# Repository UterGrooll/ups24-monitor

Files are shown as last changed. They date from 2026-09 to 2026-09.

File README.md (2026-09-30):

# UPS 24V Monitor

Контроллер мониторинга ИБП **Штиль PS2420G** на Arduino Nano: измерение напряжения шины 24 В, температуры АКБ и состояния двух сухих контактов. Данные передаются по UART на внешний контроллер для дальнейшего опроса из SCADA.

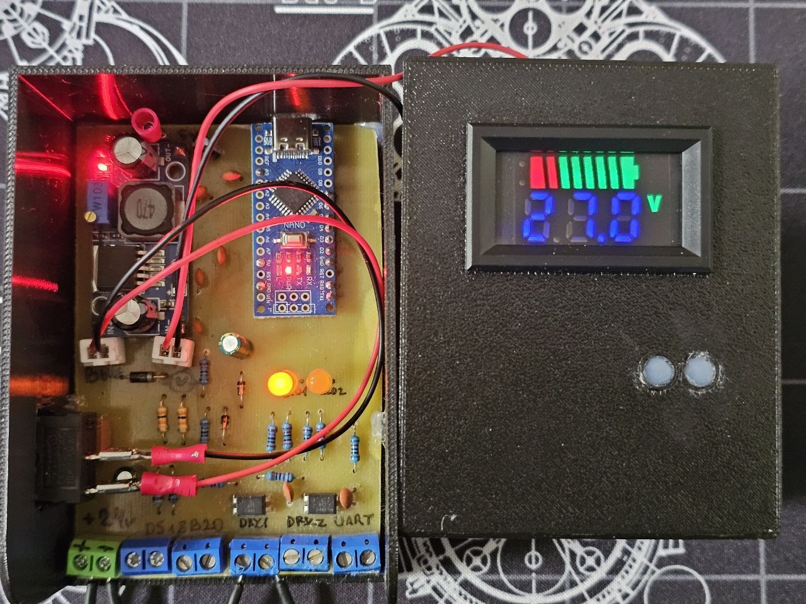
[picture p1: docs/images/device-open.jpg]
Контроллер в корпусе


## Возможности

- Один канал измерения напряжения **0…30 В**.
- Внешний датчик температуры **DS18B20**.
- Два входа сухих контактов через **PC817** с LED-индикацией.
- Выход **UART 9600 бод**, значения в целочисленном формате.
- Питание через понижающий модуль **LM2596S**, выход 5 В.
- Корпусной индикатор напряжения и съёмный выключатель.
- Плата KiCad для одностороннего травления; корпус FreeCAD и файлы 3D-печати.

> Эта плата сама не реализует Modbus TCP и не подключается к Ethernet.
> UART принимает отдельный контроллер-шлюз. Два контакта ИБП не означают два независимых канала измерения напряжения — АЦП-канал здесь один.

## Аппаратная часть

| Узел | Исполнение |
| --- | --- |
| Контроллер | Arduino Nano, ATmega328P, логика 5 В |
| Питание | Шина ИБП около 27 В → LM2596S → 5 В |
| Делитель | 30 кОм + 30 кОм / 10 кОм, номинальный коэффициент 7 |
| Температура | DS18B20, трёхпроводное подключение |
| Дискретные входы | 2 × PC817 |
| Интерфейс | Однонаправленный TTL UART |
| Проект платы | KiCad 10 |
| Корпус | FreeCAD, 3MF |

### Выводы Nano

| Сигнал | Пин |
| --- | --- |
| Напряжение через делитель | A0 |
| DS18B20 DATA | D7 |
| Контакт ИБП 1 | D6 |
| Контакт ИБП 2 | D5 |
| UART TX | D1/TX |
| Общий провод | GND |

D0/RX для текущей прошивки не используется. Пины относятся к **измерительной Nano**, не к внешнему ПАК.

## Фотографии

| Плата | Проверка UART |
| --- | --- |
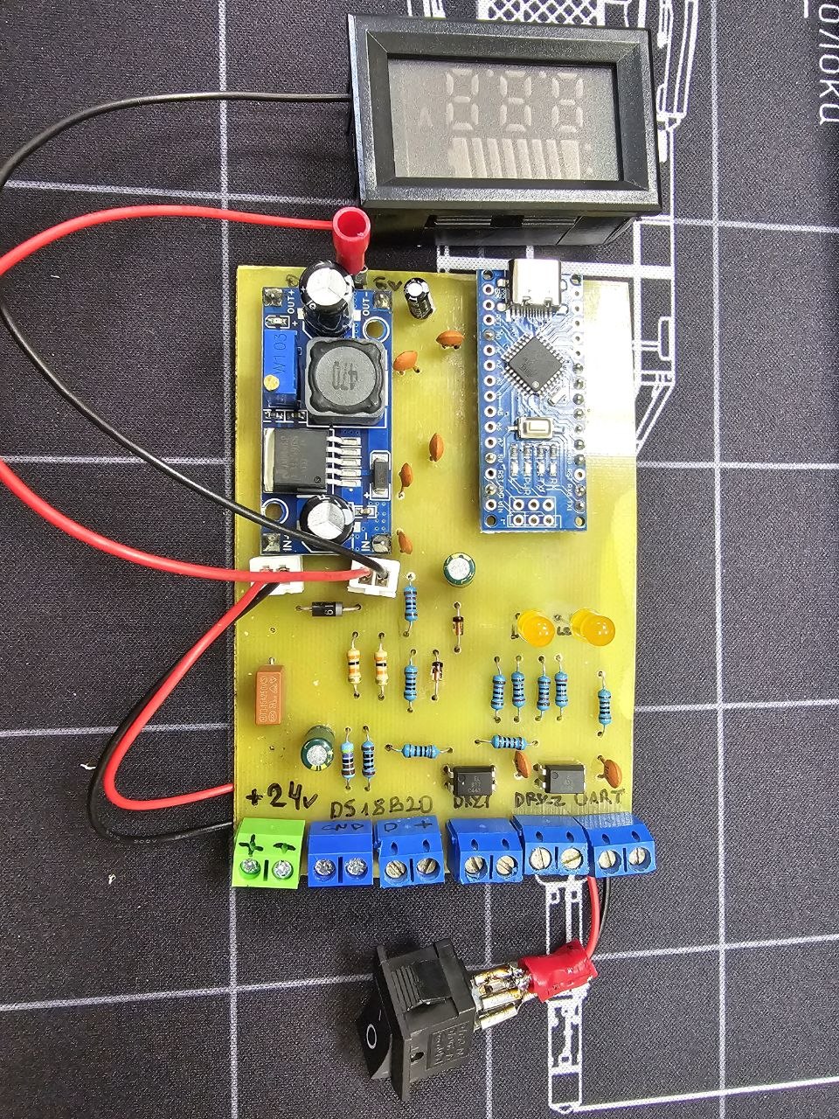
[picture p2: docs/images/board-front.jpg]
Плата
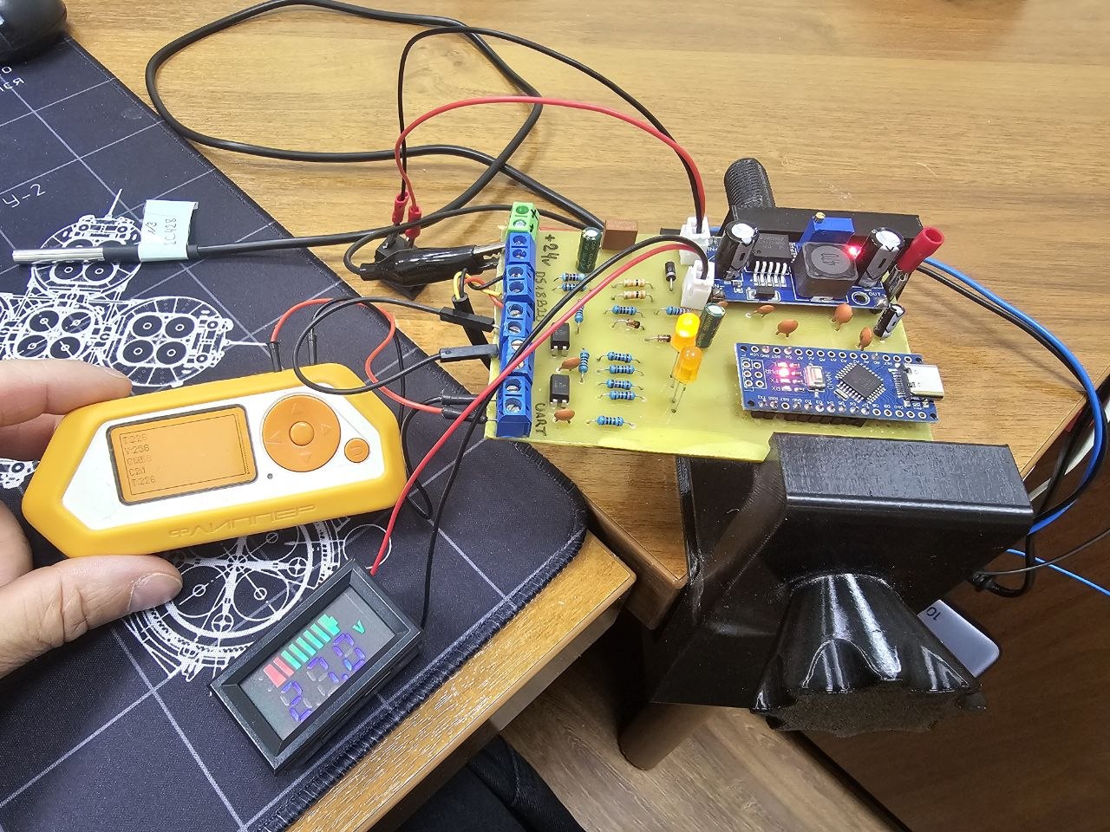
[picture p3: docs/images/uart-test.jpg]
Стендовая проверка
|  |  |

| Разводка | Корпус |
| --- | --- |
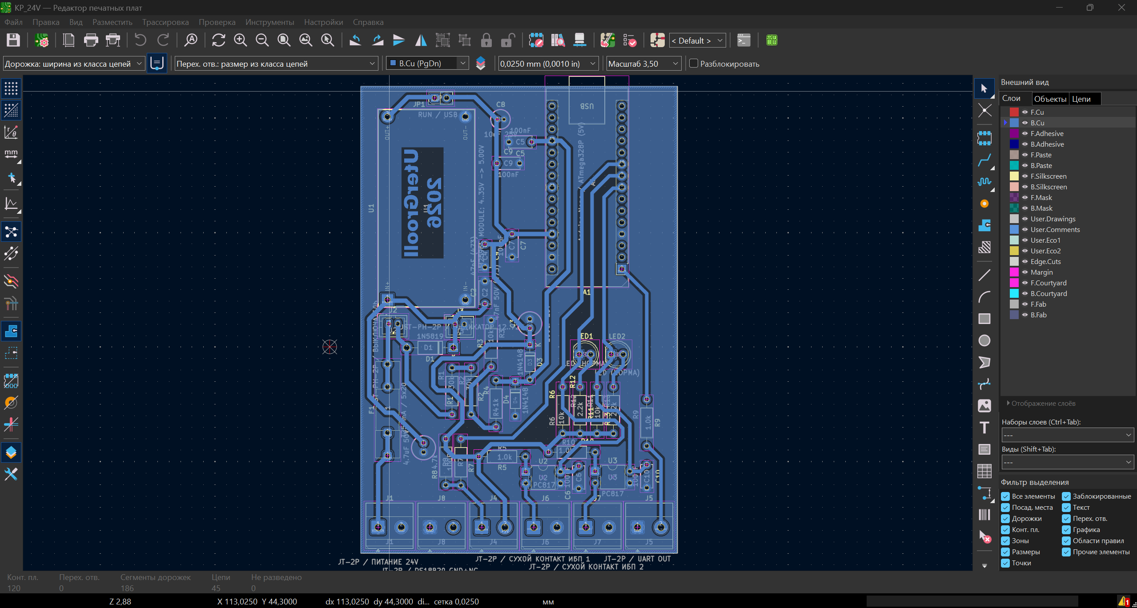
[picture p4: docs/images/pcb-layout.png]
Разводка платы
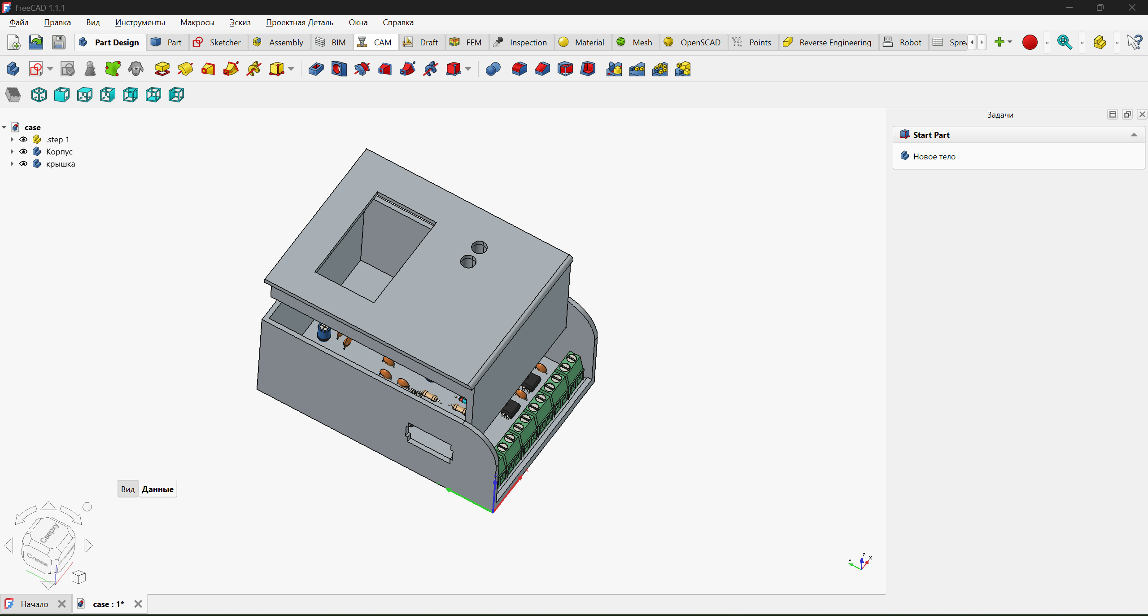
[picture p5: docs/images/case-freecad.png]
Корпус FreeCAD
|  |  |

[Все фотографии и изображения](docs/images/) взяты из материалов сборки. Фото и скриншоты могут отражать промежуточные этапы; перед изготовлением сверяйте их с исходниками KiCad.

## Прошивка

Скетч: [firmware/KP_24V/KP_24V.ino](firmware/KP_24V/KP_24V.ino).

1. Открыть скетч в Arduino IDE.
2. Установить библиотеку **GyverDS18**.
3. Выбрать Arduino Nano и загрузчик, соответствующий установленной плате.
4. Проверить безопасное питание при USB-подключении, затем загрузить скетч.
5. Открыть монитор порта на **9600 бод**.

Библиотеки Ethernet и ModbusTCP_RU на этой Nano не требуются. Логика существующего скетча при подготовке репозитория не изменялась.

### Калибровка напряжения

В скетче сохранена двухточечная калибровка конкретного макета:

| Входное напряжение | Значение АЦП |
| --- | ---: |
| 5,0 В | 144 |
| 30,0 В | 880 |

Константы `VOLTAGE_CAL_LOW_DV = 50` и `VOLTAGE_CAL_HIGH_DV = 300` заданы в десятых долях вольта. Для другой платы и источника 5 В нужно повторить измерения и изменить калибровку. Шаг вывода 0,1 В не означает гарантированную точность 0,1 В.

## UART и SCADA

Пример потока:

```text
V:270
T:234
C1:0
C2:1
```

Это 27,0 В, 23,4 °C, нормальное состояние ИБП 1 и авария/размыкание контакта ИБП 2.

Полный формат, подключение и различия карт регистров внешних приёмников описаны в [docs/uart.md](docs/uart.md).

Для стендового Modbus TCP-приёмника используется отдельный проект [SCADA Modbus TCP Relay Timer](https://github.com/UterGrooll/scada-modbus-tcp-relay-timer) на базе [ModbusTCP_RU](https://github.com/UterGrooll/ModbusTCP_RU). Исходники этого приёмника не включены в данный репозиторий.

## Схема, плата и корпус

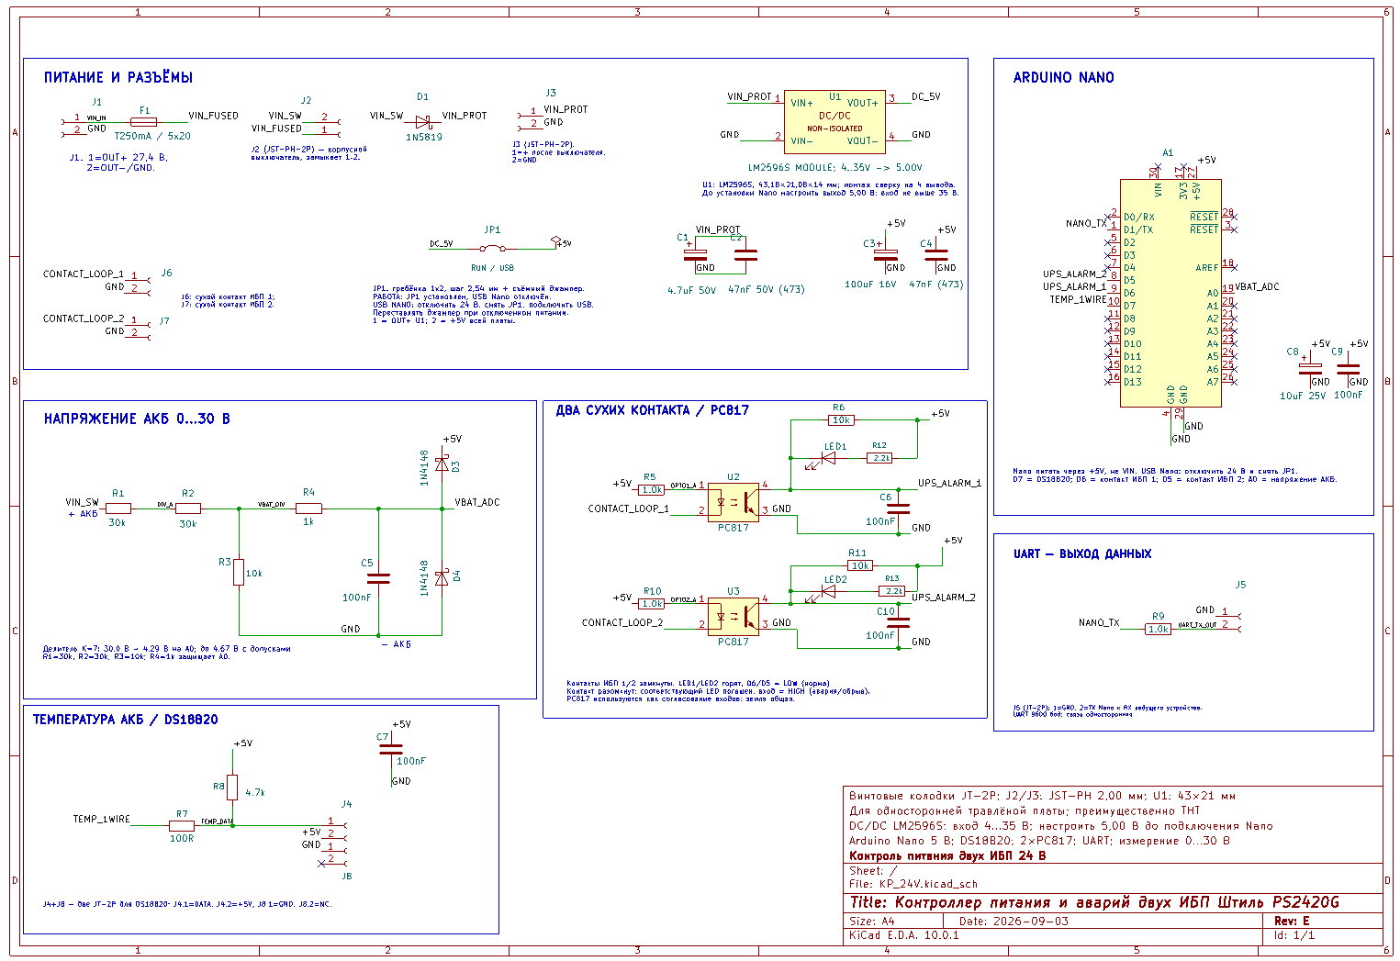
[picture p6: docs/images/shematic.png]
Принципиальная схема контроллера


Нажмите на схему, чтобы открыть изображение в полном размере.

- [Проект KiCad](schematic/KP_24V/KP_24V.kicad_pro)
- [Принципиальная схема](schematic/KP_24V/KP_24V.kicad_sch)
- [Печатная плата](schematic/KP_24V/KP_24V.kicad_pcb)
- [Примечания по аппаратной части](schematic/KP_24V/README_CONTROLLER_RU.md)
- [Модель корпуса FreeCAD](case/case.FCStd)
- [Основание для печати](case/case-Body.3mf)
- [Крышка для печати](case/case-крышка.3mf)

Локальные библиотеки символов и посадочных мест сохранены рядом с KiCad-проектом; пути используют `${KIPRJMOD}`.

## Ограничения и безопасное подключение

- Перед установкой Nano настроить DC/DC на **5,00 В**. Не подавать 24–30 В непосредственно на вывод 5V или A0.
- Для USB Nano отключить внешние 24 В и снять **JP1** между OUT+ DC/DC и шиной +5 В. Проверить, что джампер действительно разрывает эту цепь на собранной плате.
- Перед изменением соединений отключить все источники питания, включая USB. Подпитка возможна и через сигнальные линии.
- PC817 не обеспечивает развязку всего устройства: GND питания, Nano и UART общий.
- UART рассчитан на короткое соединение; линия не является RS-232 или RS-485.
- В текущем скетче нет антидребезга контактов. После потери DS18B20 повторный запуск измерений не гарантирован: внешний приёмник должен контролировать свежесть каждого канала.
- Это авторский прототип мониторинга, а не устройство защиты АКБ или сертифицированный промышленный контроллер.

## Структура

```text
firmware/KP_24V/     Прошивка измерительной Nano
schematic/KP_24V/    KiCad: схема, PCB, локальные библиотеки
case/               FreeCAD и файлы корпуса
docs/images/        Фотографии и скриншоты сборки
docs/uart.md        Формат UART и интеграция
```

Резервные копии CAD, локальная история, старые отчёты, Word-документы и материалы «Подключение» исключены из Git.

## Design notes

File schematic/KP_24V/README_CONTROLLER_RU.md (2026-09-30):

# Аппаратная часть KP_24V

Этот файл описывает текущие исходники KiCad, а не первоначальный черновик схемы. Проект содержит схему, разведённую PCB и локальные библиотеки.

## Основные узлы

- Arduino Nano, ATmega328P, питание 5 В.
- LM2596S: понижение напряжения шины ИБП до 5 В; настройка до подключения Nano.
- Делитель A0: R1 = 30 кОм, R2 = 30 кОм, R3 = 10 кОм; K = 7. R4 = 1 кОм в цепи АЦП, C5 = 100 нФ, защитные диоды D3/D4 = 1N4148.
- Два входа сухих контактов на PC817.
- DS18B20 с подтяжкой 4,7 кОм.
- Однонаправленный UART, TX Nano через 1 кОм.
- JP1: съёмный джампер, 1×2, шаг 2,54 мм, между OUT+ DC/DC и +5 В платы.

Пины Nano: A0 — напряжение, D7 — DS18B20, D6 — ИБП 1, D5 — ИБП 2, D1/TX — UART.

Измеряется одна коммутируемая шина питания, а не две независимые АКБ. Полной гальванической развязки с ИБП и UART нет.

## Локальные библиотеки

`fp-lib-table` и `sym-lib-table` используют относительный путь `${KIPRJMOD}`. Каталог `Arduino_MountingHole.pretty` и файл `KP_24V.kicad_sym` переносить вместе с проектом.

Модуль DC/DC: посадочное место `LM2596S_Module_43x21_P40x17`, прямоугольник контактных отверстий 40×17 мм, габарит платы около 43×21 мм. Перед изготовлением сверить реальные размеры своего модуля и разъёмов.

## Питание и USB

Для работы от ИБП JP1 установлен, USB Nano отключён. Для программирования от USB отключить внешние 24 В, снять JP1 и проверить отсутствие обходной дорожки OUT+ → +5 В. Менять джампер только при отключённых источниках питания.

JP1 разрывает питание от преобразователя, но не обеспечивает гальваническую развязку. Перед изменением монтажа отключить USB, внешнее питание и сигнальные подключения к запитанным устройствам.

## Перед изготовлением

1. Открыть KiCad-проект и сверить распиновку фактических компонентов.
2. Проверить схему и соответствие PCB, выполнить ERC/DRC.
3. Проверить размеры при печати 1:1 и сторону переноса рисунка для своего способа травления.
4. Проверить полярность, отсутствие коротких замыканий и выход DC/DC 5,00 В до установки Nano.
5. Повторить калибровку напряжения для собранной платы.

При подготовке репозитория электрическая схема, PCB и прошивка не изменялись; новая электрическая проверка или аппаратные испытания не выполнялись. Старые PDF, BOM, netlist и отчёт ERC исключены из Git, поскольку предшествуют текущей редакции. При необходимости сформировать их заново из исходников.

Описание устройства: [README](../../README.md). Формат передачи: [UART](../../docs/uart.md).

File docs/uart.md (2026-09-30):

# UART и интеграция со SCADA

## Подключение

Плата KP_24V только передаёт данные. Общие параметры: **9600 бод, 8N1**, текст ASCII, окончание строки **CRLF**.

- J5.2 UART_TX_OUT → RX внешнего приёмника с логикой 5 В.
- J5.1 GND → GND приёмника.
- Последовательный резистор 1 кОм уже предусмотрен на выходе Nano; на макете без этой цепи его устанавливают отдельно.
- Питания +5 В двух устройств не объединять автоматически; при подключённой линии обе стороны должны быть запитаны.
- Для приёмника с логикой 3,3 В необходимо согласование уровней.

Вывод D8 используется как RX в обоих описанных ниже внешних приёмниках. Не путать пины внешнего контроллера с пинами самой Nano.

## Формат

| Строка | Значение |
| --- | --- |
| `V:270` | Напряжение 27,0 В |
| `T:234` | Температура 23,4 °C |
| `T:-55` | Температура −5,5 °C |
| `T:32767` | Ошибка чтения DS18B20 |
| `C1:0` / `C2:0` | Контакт соответствующего ИБП замкнут, норма |
| `C1:1` / `C2:1` | Контакт разомкнут, авария или обрыв цепи |

V, C1 и C2 отправляются раз в 500 мс. T отправляется отдельно после завершения измерения датчиком. Порядок строк не является атомарным снимком всех каналов.

Контактная логика должна быть проверена на конкретном ИБП. Передавать на вход сухого контакта внешнее напряжение нельзя.

## Внешний приёмник определяет карту Modbus

У измерительной Nano нет собственных регистров Modbus. У двух использованных приёмников разные карты. Все адреса ниже **с нуля**, функция **FC04**.

| Данные | Стенд ScadaRelayTimer | ПАК plc-prs10 |
| --- | ---: | ---: |
| Напряжение KP_24V | 3 | 1 |
| Температура АКБ KP_24V | 4 | 2 |
| Авария ИБП 1 | 5 | 3 |
| Авария ИБП 2 | 6 | 4 |
| Маска достоверности KP_24V | нет | 5 |

В ПАК адрес 0 сохранён за его местным DS18B20. Контакты D2–D5 ПАК опрашиваются отдельно через FC02 и не являются контактами C1/C2 измерительной Nano.

Для ПАК: Modbus Poll → FC04, Address 0, Quantity 6. Для стенда: FC04, Address 0, Quantity 7. Адрес сервера определяется прошивкой соответствующего приёмника.

Температура — signed 16-bit; напряжение, контакты и маска — unsigned 16-bit. Напряжение и температуру делить на 10. В редакторе с адресацией «начиная с 1» к приведённым адресам прибавить 1.

## Достоверность

Приёмник ПАК использует независимый таймаут 5 с для каждого канала. Маска FC04/5:

- бит 0 (1): напряжение;
- бит 1 (2): температура АКБ;
- бит 2 (4): контакт ИБП 1;
- бит 3 (8): контакт ИБП 2.

15 = все данные актуальны. 13 = актуальны напряжение и контакты, температура недостоверна. 0 = нет актуальных данных.

32767 для температуры и 65535 для напряжения/контактов — коды ошибки, а не физические значения. Их нельзя отображать после обычного масштабирования.

Текущая Nano при потере DS18B20 может перестать отправлять T до перезапуска, поэтому факт прихода V/C1/C2 не подтверждает исправность температуры. Стендовый ScadaRelayTimer не следует считать эквивалентом ПАК по контролю свежести: в рассмотренной стендовой версии отсутствует такой поканальный таймаут.

## Ограничения протокола

Нет контрольной суммы, номера пакета и подтверждения доставки. Приёмник должен проверять формат, диапазоны и возраст данных. Одного наличия UART-трафика недостаточно для признания всех измерений достоверными.

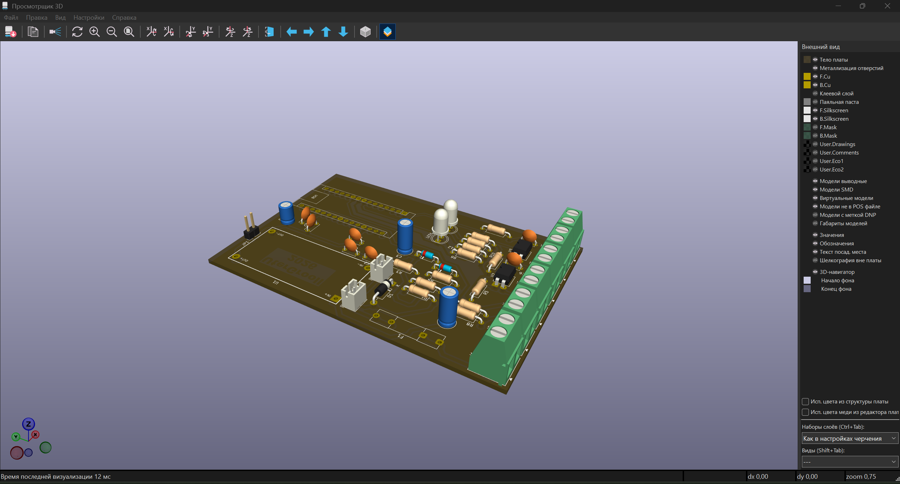
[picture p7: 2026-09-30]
docs/images/pcb-3d.png

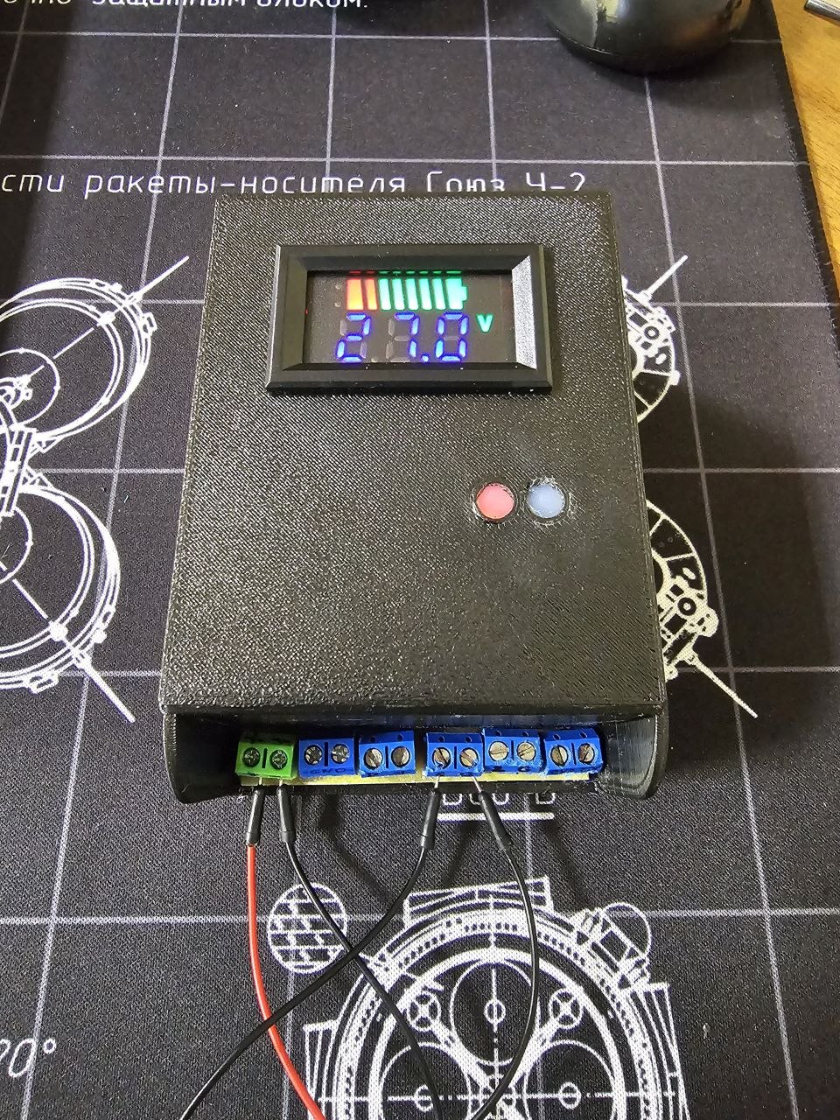
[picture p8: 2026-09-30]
docs/images/device-open-2.jpg

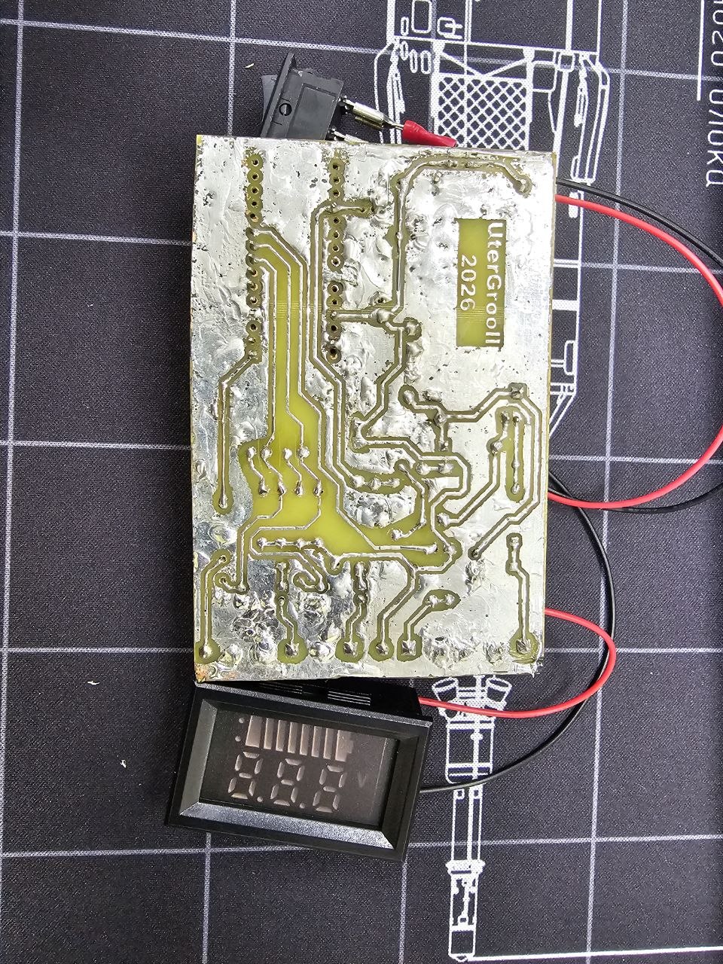
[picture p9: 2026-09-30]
docs/images/board-front-2.jpg

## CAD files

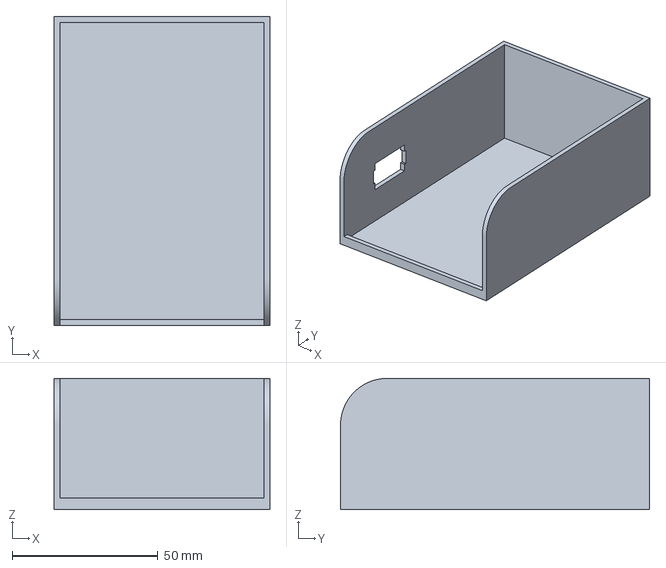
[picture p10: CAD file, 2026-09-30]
case/case-Body.3mf
74.0 x 106.0 x 45.0 mm

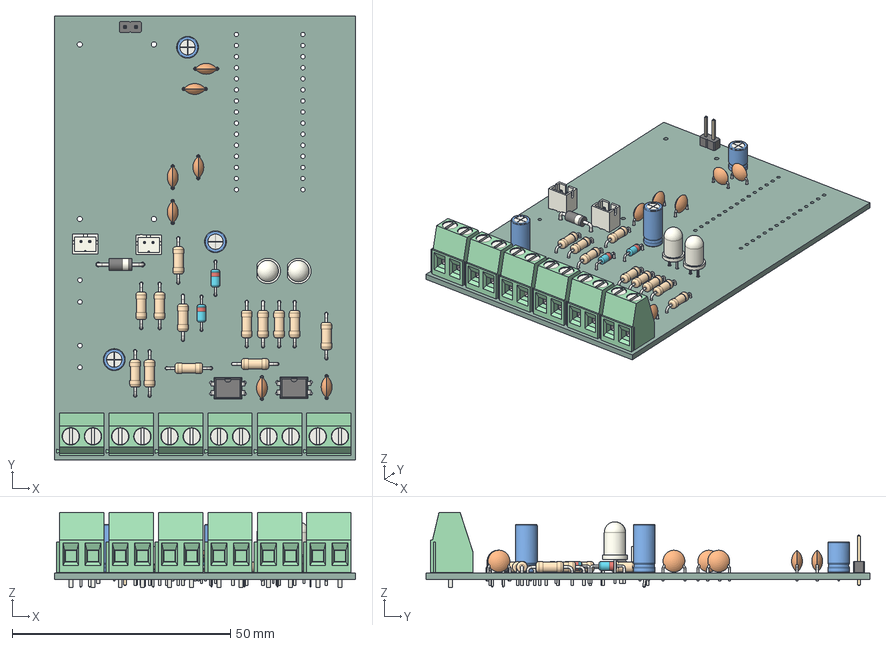
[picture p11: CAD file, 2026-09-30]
case/.step
69.0 x 101.8 x 17.3 mm
R_Axial_DIN0207_L6.3mm_D2.5mm_P10.16mm_Horizontal x 13
C_Disc_D5.0mm_W2.5mm_P5.00mm x 7
C_Radial_D5.0mm_H11.0mm_P2.00mm x 2
DIP-4_W7.62mm x 2
D_DO-41_SOD81_P10.16mm_Horizontal
JST_PH_B2B-PH-K_1x02_P2.00mm_Vertical x 2
TerminalBlock_Phoenix_MKDS-1,5-2-5.08_1x02_P5.08mm_Horizontal x 6
LED_D5.0mm_Clear x 2
C_Radial_D4.0mm_H7.0mm_P1.50mm
PinHeader_1x02_P2.54mm_Vertical
D_DO-35_SOD27_P7.62mm_Horizontal x 2
KP_24V_PCB

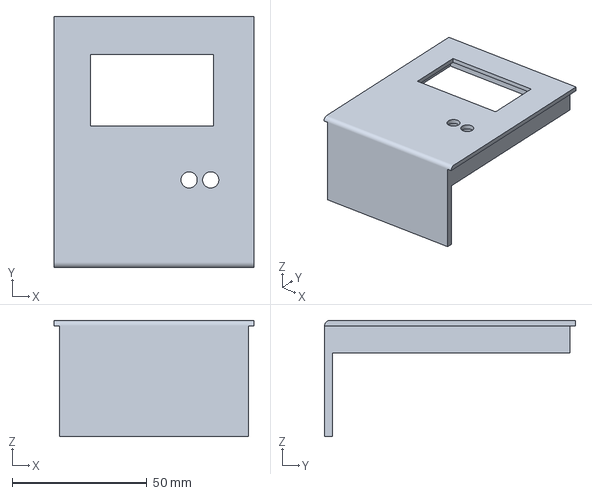
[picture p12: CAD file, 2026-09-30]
case/case-крышка.3mf
74.0 x 93.0 x 43.0 mm

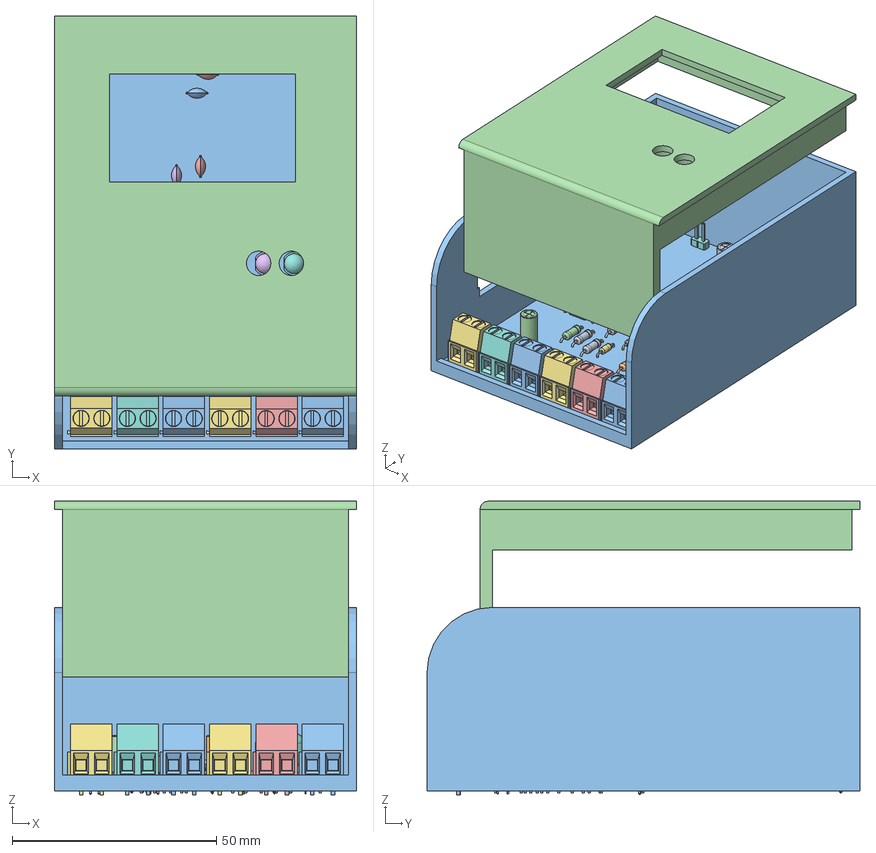
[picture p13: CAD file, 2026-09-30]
case/case.FCStd
74.0 x 106.0 x 71.9 mm
R_Axial_DIN0207_L6.3mm_D2.5mm_P10.16mm_Horizontal
R_Axial_DIN0207_L6.3mm_D2.5mm_P10.16mm_Horizontal001
C_Disc_D5.0mm_W2.5mm_P5.00mm
C_Radial_D5.0mm_H11.0mm_P2.00mm
C_Disc_D5.0mm_W2.5mm_P5.00mm001
C_Disc_D5.0mm_W2.5mm_P5.00mm002
DIP-4_W7.62mm
D_DO-41_SOD81_P10.16mm_Horizontal
R_Axial_DIN0207_L6.3mm_D2.5mm_P10.16mm_Horizontal002
JST_PH_B2B-PH-K_1x02_P2.00mm_Vertical
TerminalBlock_Phoenix_MKDS-1,5-2-5.08_1x02_P5.08mm_Horizontal
R_Axial_DIN0207_L6.3mm_D2.5mm_P10.16mm_Horizontal003
C_Disc_D5.0mm_W2.5mm_P5.00mm003
LED_D5.0mm_Clear
TerminalBlock_Phoenix_MKDS-1,5-2-5.08_1x02_P5.08mm_Horizontal001
LED_D5.0mm_Clear001
C_Radial_D4.0mm_H7.0mm_P1.50mm
R_Axial_DIN0207_L6.3mm_D2.5mm_P10.16mm_Horizontal004
TerminalBlock_Phoenix_MKDS-1,5-2-5.08_1x02_P5.08mm_Horizontal002
R_Axial_DIN0207_L6.3mm_D2.5mm_P10.16mm_Horizontal005
C_Disc_D5.0mm_W2.5mm_P5.00mm004
C_Disc_D5.0mm_W2.5mm_P5.00mm005
TerminalBlock_Phoenix_MKDS-1,5-2-5.08_1x02_P5.08mm_Horizontal003
PinHeader_1x02_P2.54mm_Vertical
R_Axial_DIN0207_L6.3mm_D2.5mm_P10.16mm_Horizontal006
R_Axial_DIN0207_L6.3mm_D2.5mm_P10.16mm_Horizontal007
JST_PH_B2B-PH-K_1x02_P2.00mm_Vertical001
R_Axial_DIN0207_L6.3mm_D2.5mm_P10.16mm_Horizontal008
TerminalBlock_Phoenix_MKDS-1,5-2-5.08_1x02_P5.08mm_Horizontal004
R_Axial_DIN0207_L6.3mm_D2.5mm_P10.16mm_Horizontal009
D_DO-35_SOD27_P7.62mm_Horizontal
D_DO-35_SOD27_P7.62mm_Horizontal001
R_Axial_DIN0207_L6.3mm_D2.5mm_P10.16mm_Horizontal010
C_Radial_D5.0mm_H11.0mm_P2.00mm001
C_Disc_D5.0mm_W2.5mm_P5.00mm006
DIP-4_W7.62mm001
R_Axial_DIN0207_L6.3mm_D2.5mm_P10.16mm_Horizontal011
D_DO-35_SOD27_P7.62mm_Horizontal003
D_DO-35_SOD27_P7.62mm_Horizontal004
TerminalBlock_Phoenix_MKDS-1,5-2-5.08_1x02_P5.08mm_Horizontal005
R_Axial_DIN0207_L6.3mm_D2.5mm_P10.16mm_Horizontal012
KP_24V_PCB
Корпус
крышка

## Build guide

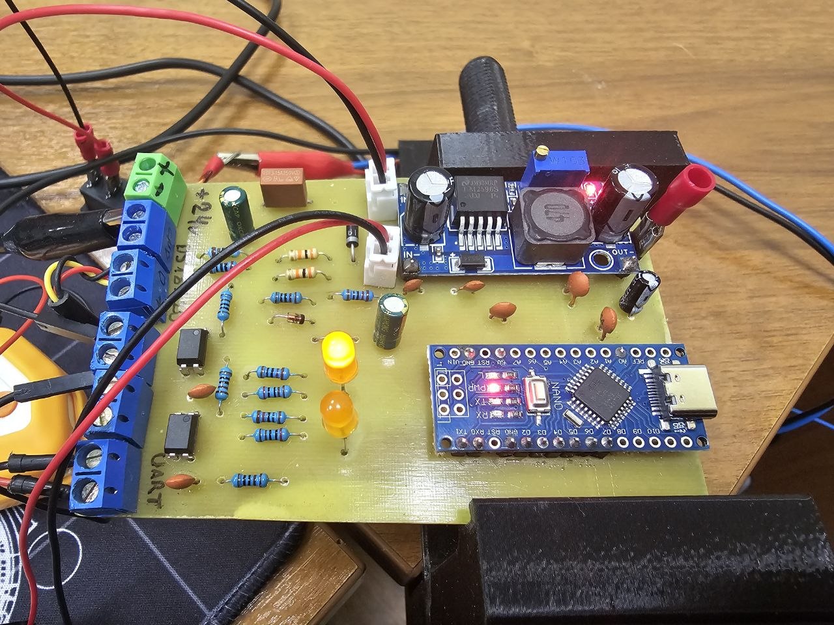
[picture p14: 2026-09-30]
docs/images/assembly-detail.jpg

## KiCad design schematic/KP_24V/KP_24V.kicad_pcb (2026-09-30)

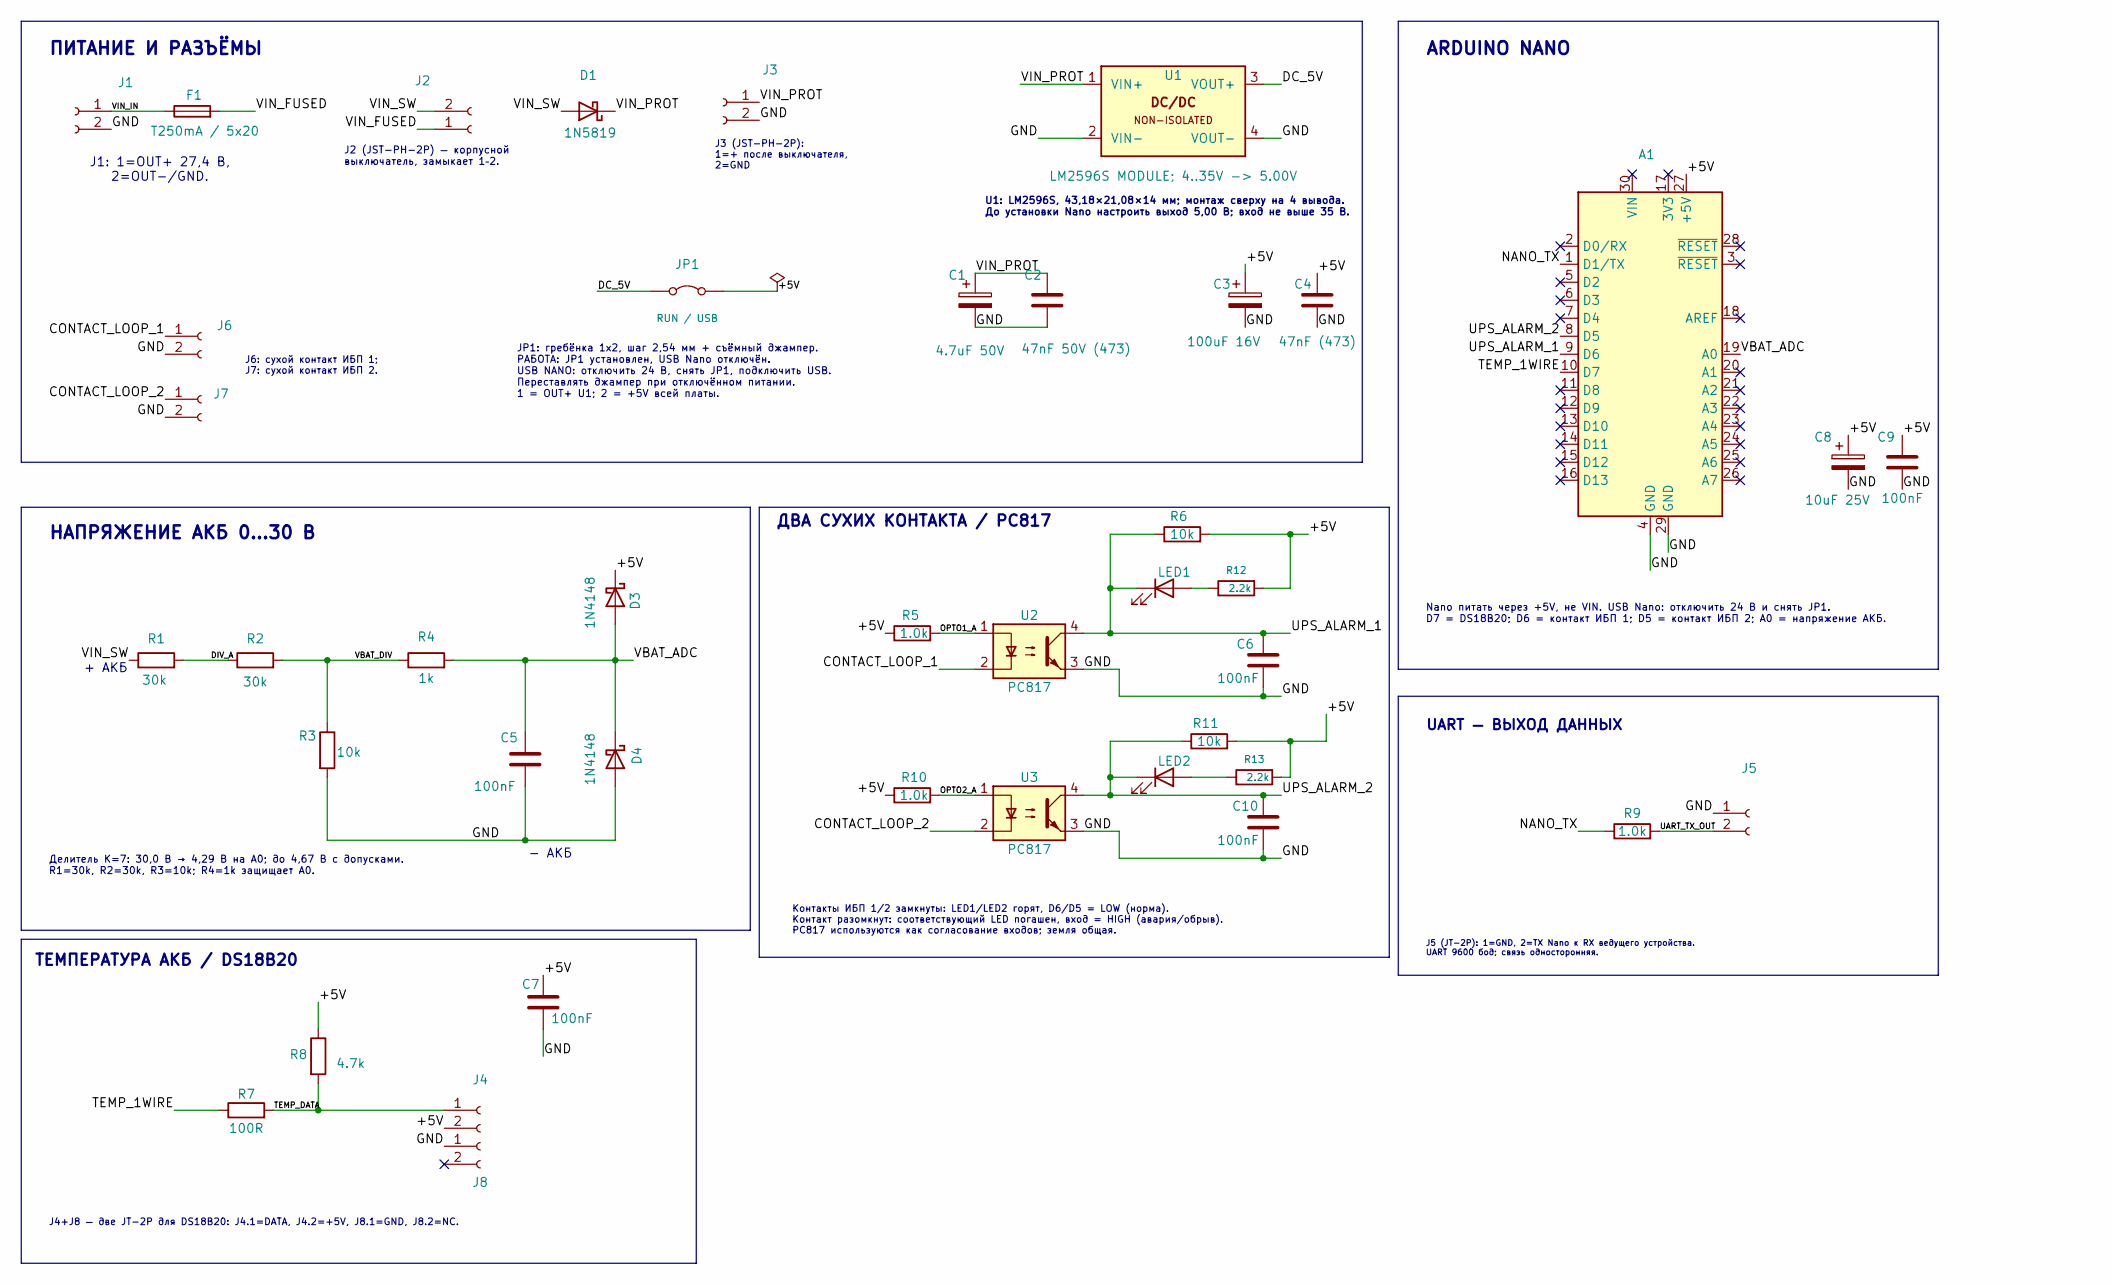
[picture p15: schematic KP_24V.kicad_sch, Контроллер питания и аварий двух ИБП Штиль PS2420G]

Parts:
A1: Arduino Nano / ATmega328P (5V); Arduino_Nano
C1: 4.7uF 50V; C_Radial_D5.0mm_H11.0mm_P2.00mm
C2: 47nF 50V (473); C_Disc_D5.0mm_W2.5mm_P5.00mm
C3: 100uF 16V; C_Radial_D5.0mm_H11.0mm_P2.00mm
C4: 47nF (473); C_Disc_D5.0mm_W2.5mm_P5.00mm
C5, C6, C7, C9, C10: 100nF; C_Disc_D5.0mm_W2.5mm_P5.00mm
C8: 10uF 25V; C_Radial_D4.0mm_H7.0mm_P1.50mm
D1: 1N5819; D_DO-41_SOD81_P10.16mm_Horizontal
D3, D4: 1N4148; D_DO-35_SOD27_P7.62mm_Horizontal
F1: T250mA / 5x20; Fuseholder_Clip-5x20mm_Littelfuse_111_Inline_P20.00x5.00mm_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
J1: JT-2P / ПИТАНИЕ 24V; TerminalBlock_Phoenix_MKDS-1,5-2-5.08_1x02_P5.08mm_Horizont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
J2: JST-PH-2P / ВЫКЛЮЧАТЕЛЬ; JST_PH_B2B-PH-K_1x02_P2.00mm_Vertical
J3: JST-PH-2P / ИНДИКАТОР 12..72V; JST_PH_B2B-PH-K_1x02_P2.00mm_Vertical
J4: JT-2P / DS18B20 DATA+5V; TerminalBlock_Phoenix_MKDS-1,5-2-5.08_1x02_P5.08mm_Horizont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
J5: JT-2P / UART OUT; TerminalBlock_Phoenix_MKDS-1,5-2-5.08_1x02_P5.08mm_Horizont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
J6: JT-2P / СУХОЙ КОНТАКТ ИБП 1; TerminalBlock_Phoenix_MKDS-1,5-2-5.08_1x02_P5.08mm_Horizont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
J7: JT-2P / СУХОЙ КОНТАКТ ИБП 2; TerminalBlock_Phoenix_MKDS-1,5-2-5.08_1x02_P5.08mm_Horizont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
J8: JT-2P / DS18B20 GND+NC; TerminalBlock_Phoenix_MKDS-1,5-2-5.08_1x02_P5.08mm_Horizont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
JP1: RUN / USB; PinHeader_1x02_P2.54mm_Vertical
LED1, LED2: LED (НОРМА); LED_D5.0mm_Clear
R1, R2: 30k; R_Axial_DIN0207_L6.3mm_D2.5mm_P10.16mm_Horizontal
R3, R6, R11: 10k; R_Axial_DIN0207_L6.3mm_D2.5mm_P10.16mm_Horizontal
R4: 1k; R_Axial_DIN0207_L6.3mm_D2.5mm_P10.16mm_Horizontal
R5, R9, R10: 1.0k; R_Axial_DIN0207_L6.3mm_D2.5mm_P10.16mm_Horizontal
R7: 100R; R_Axial_DIN0207_L6.3mm_D2.5mm_P10.16mm_Horizontal
R8: 4.7k; R_Axial_DIN0207_L6.3mm_D2.5mm_P10.16mm_Horizontal
R12, R13: 2.2k; R_Axial_DIN0207_L6.3mm_D2.5mm_P10.16mm_Horizontal; PartNumber RC0805FR-07510RL
U1: LM2596S MODULE; 4..35V -> 5.00V; LM2596S_Module_43x21_P40x17
U2, U3: PC817; DIP-4_W7.62mm

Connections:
/+5V: A1.27 (+5V), C3.1, C4.1, C7.1, C8.1, C9.1, D3.1 (K), J4.2, JP1.2 (B), R5.1, R6.2, R8.1, R10.1, R11.2, R12.2, R13.2
/CONTACT_LOOP_1: J6.1, U2.2
/CONTACT_LOOP_2: J7.1, U3.2
/DC_5V: JP1.1 (A), U1.3 (VOUT+)
/DIV_A: R1.2, R2.1
/GND: A1.4 (GND), A1.29 (GND), C1.2, C2.2, C3.2, C4.2, C5.2, C6.2, C7.2, C8.2, C9.2, C10.2, D4.2 (A), J1.2, J3.2, J5.1, J6.2, J7.2, J8.1 (Pin_1_1), R3.2, U1.2 (VIN-), U1.4 (VOUT-), U2.3, U3.3
/NANO_TX: A1.1 (D1/TX), R9.1
/OPTO1_A: R5.2, U2.1
/OPTO2_A: R10.2, U3.1
/TEMP_1WIRE: A1.10 (D7), R7.1
/TEMP_DATA: J4.1, R7.2, R8.2
/UART_TX_OUT: J5.2, R9.2
/UPS_ALARM_1: A1.9 (D6), C6.1, LED1.1 (K), R6.1, U2.4
/UPS_ALARM_2: A1.8 (D5), C10.1, LED2.1 (K), R11.1, U3.4
/VBAT_ADC: A1.19 (A0), C5.1, D3.2 (A), D4.1 (K), R4.2
/VBAT_DIV: R2.2, R3.1, R4.1
/VIN_FUSED: F1.2, J2.1
/VIN_IN: F1.1, J1.1
/VIN_PROT: C1.1, C2.1, D1.1 (K), J3.1, U1.1 (VIN+)
/VIN_SW: D1.2 (A), J2.2, R1.1
unnamed: LED1.2 (A), R12.1
unnamed: LED2.2 (A), R13.1

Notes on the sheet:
ТЕМПЕРАТУРА АКБ / DS18B20
Контакты ИБП 1/2 замкнуты: LED1/LED2 горят, D6/D5 = LOW (норма). Контакт разомкнут: соответствующий LED погашен, вход = HIGH (авария/обрыв). PC817 используются как согласование входов; земля общая.
J5 (JT-2P): 1=GND, 2=TX Nano к RX ведущего устройства. UART 9600 бод; связь односторонняя.
Nano питать через +5V, не VIN. USB Nano: отключить 24 В и снять JP1. D7 = DS18B20; D6 = контакт ИБП 1; D5 = контакт ИБП 2; A0 = напряжение АКБ.
Делитель K=7: 30,0 В → 4,29 В на A0; до 4,67 В с допусками. R1=30k, R2=30k, R3=10k; R4=1k защищает A0.
J4+J8 — две JT-2P для DS18B20: J4.1=DATA, J4.2=+5V, J8.1=GND, J8.2=NC.
+ АКБ
J3 (JST-PH-2P): 1=+ после выключателя, 2=GND
UART — ВЫХОД ДАННЫХ
J2 (JST-PH-2P) — корпусной выключатель, замыкает 1–2.
ARDUINO NANO
ДВА СУХИХ КОНТАКТА / PC817
- АКБ
U1: LM2596S, 43,18×21,08×14 мм; монтаж сверху на 4 вывода. До установки Nano настроить выход 5,00 В; вход не выше 35 В.
JP1: гребёнка 1x2, шаг 2,54 мм + съёмный джампер. РАБОТА: JP1 установлен, USB Nano отключён. USB NANO: отключить 24 В, снять JP1, подключить USB. Переставлять джампер при отключённом питании. 1 = OUT+ U1; 2 = +5V всей платы.
НАПРЯЖЕНИЕ АКБ 0…30 В
ПИТАНИЕ И РАЗЪЁМЫ
J1: 1=OUT+ 27,4 В, 2=OUT−/GND.
J6: сухой контакт ИБП 1; J7: сухой контакт ИБП 2.

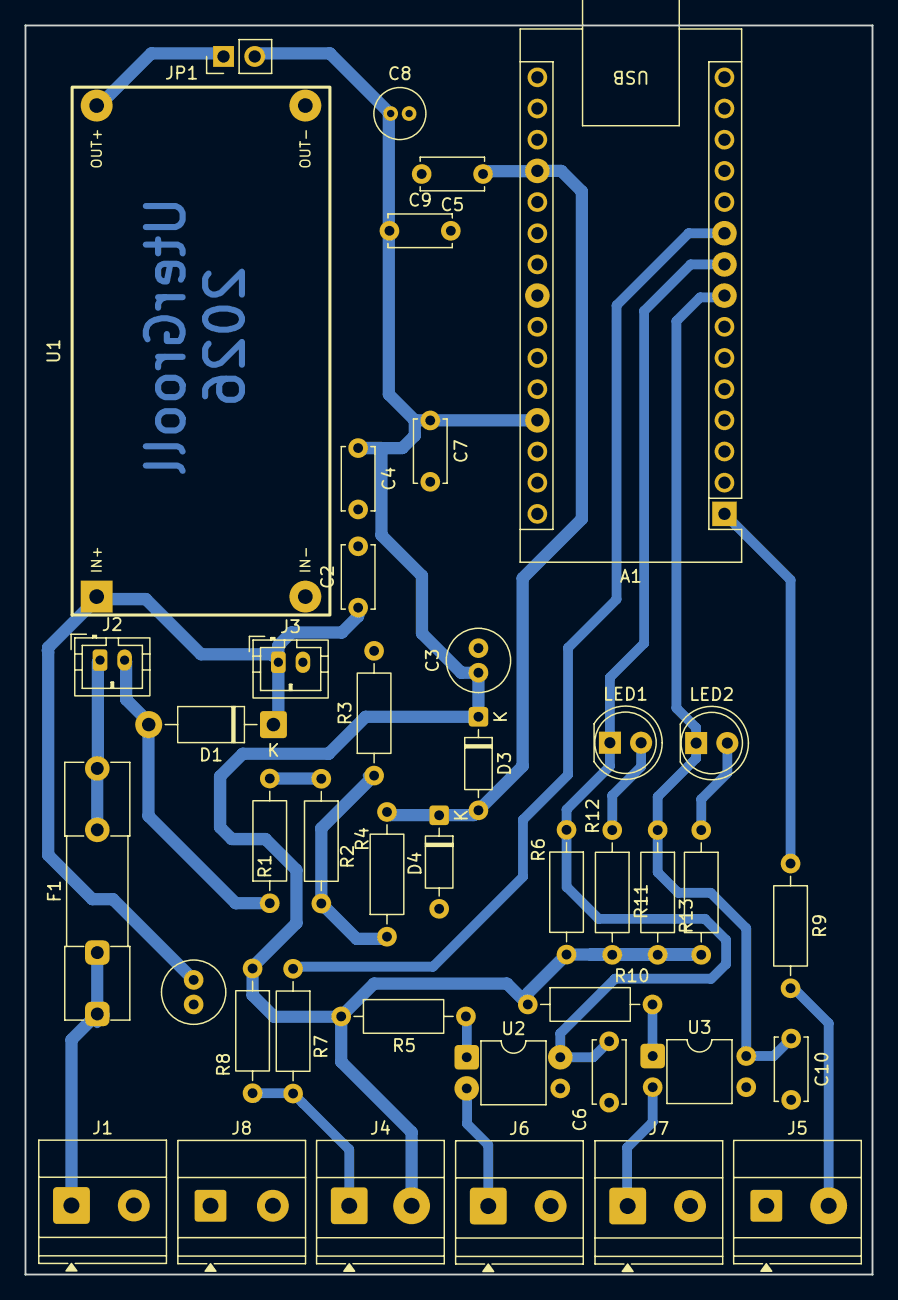
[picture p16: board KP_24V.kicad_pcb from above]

Board: 2 copper layers, 69.0 x 101.8 mm, 42 parts (0 on the bottom side), 22 nets.

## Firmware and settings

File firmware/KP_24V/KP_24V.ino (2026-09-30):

/*
  KP_24V test firmware for Arduino Nano

  Reads the battery voltage from A0, a DS18B20 temperature sensor on D7,
  and two PS2420G dry-contact states through PC817 optocouplers on D6/D5.
  Periodically sends scaled integer values as ASCII frames:

    V:<voltage in tenths of a volt>\r\n
    T:<temperature in tenths of a degree Celsius>\r\n
    C1:<UPS 1 alarm: 0 = normal, 1 = alarm/contact open>\r\n
    C2:<UPS 2 alarm: 0 = normal, 1 = alarm/contact open>\r\n

  Examples: 20.0 V is sent as V:200; 23.4 C is sent as T:234.

  Bench wiring:
    Nano D1/TX -> 1 kOhm -> main Arduino Uno D8/RX
    Nano GND   -> main Arduino Uno GND

    DS18B20 VCC  -> Nano +5V
    DS18B20 DATA -> Nano D7
    DS18B20 GND  -> Nano GND
    4.7 kOhm between DATA and +5V

  D0/RX is not required for this one-way test.
*/

#include <GyverDS18.h>

const byte ANALOG_INPUT_PIN = A0;
const byte DS18B20_PIN = 7;
const byte UPS1_ALARM_INPUT_PIN = 6;
const byte UPS2_ALARM_INPUT_PIN = 5;
const unsigned long SEND_INTERVAL_MS = 500UL;
const int16_t TEMPERATURE_ERROR_VALUE = 32767;

// Bench calibration with USB power and the assembled 30k + 30k / 10k divider.
const int ADC_CAL_LOW = 144;
const int ADC_CAL_HIGH = 880;
const int VOLTAGE_CAL_LOW_DV = 50;
const int VOLTAGE_CAL_HIGH_DV = 300;

GyverDS18Single temperatureSensor(DS18B20_PIN, false);

unsigned long lastSendTime = 0;

uint16_t adcToDecivolts(uint16_t adc)
{
  if (adc <= 3) {
    return 0;
  }

  const int32_t adcSpan = ADC_CAL_HIGH - ADC_CAL_LOW;
  const int32_t voltageSpan = VOLTAGE_CAL_HIGH_DV - VOLTAGE_CAL_LOW_DV;
  int32_t numerator = ((int32_t)adc - ADC_CAL_LOW) * voltageSpan;

  // Round to the nearest tenth for both positive and negative offsets.
  numerator += (numerator >= 0) ? adcSpan / 2 : -adcSpan / 2;

  int32_t decivolts = VOLTAGE_CAL_LOW_DV + numerator / adcSpan;
  if (decivolts < 0) {
    decivolts = 0;
  }
  if (decivolts > 65535L) {
    decivolts = 65535L;
  }
  return (uint16_t)decivolts;
}

int16_t temperatureToTenths(int16_t rawSixteenths)
{
  int32_t scaled = (int32_t)rawSixteenths * 10L;
  scaled += (scaled >= 0) ? 8 : -8;
  return (int16_t)(scaled / 16L);
}

void sendAlarmFrame(const __FlashStringHelper *name, byte pin)
{
  // Closed UPS contact energizes the PC817, so LOW is the normal state.
  const bool alarm = digitalRead(pin) == HIGH;
  Serial.print(name);
  Serial.println(alarm ? 1 : 0);
}

void setup()
{
  Serial.begin(9600);
  pinMode(UPS1_ALARM_INPUT_PIN, INPUT_PULLUP);
  pinMode(UPS2_ALARM_INPUT_PIN, INPUT_PULLUP);
  temperatureSensor.requestTemp();
}

void loop()
{
  unsigned long now = millis();

  if (now - lastSendTime >= SEND_INTERVAL_MS) {
    lastSendTime = now;

    uint16_t rawA0 = analogRead(ANALOG_INPUT_PIN);

    Serial.print(F("V:"));
    Serial.println(adcToDecivolts(rawA0));

    sendAlarmFrame(F("C1:"), UPS1_ALARM_INPUT_PIN);
    sendAlarmFrame(F("C2:"), UPS2_ALARM_INPUT_PIN);
  }

  if (temperatureSensor.ready()) {
    Serial.print(F("T:"));

    if (temperatureSensor.readTemp()) {
      Serial.println(temperatureToTenths(temperatureSensor.getTempRaw()));
    } else {
      Serial.println(TEMPERATURE_ERROR_VALUE);
    }

    temperatureSensor.requestTemp();
  }
}

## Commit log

2026-09-30 Initial release: UPS 24V monitor hardware and firmware
    [.step, KP_24V.kicad_pcb, KP_24V.kicad_sch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]
2026-09-30 docs: add controller schematic image to README
